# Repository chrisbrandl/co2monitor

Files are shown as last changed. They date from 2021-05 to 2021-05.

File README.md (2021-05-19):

# co2monitor

An IoT project to counter the spread of Covid19 indoors. 

Scientific Background: https://pubs.acs.org/doi/10.1021/acs.estlett.1c00183

There are lots of projects online that describe the basic setup to using a specific sensor for that, but they are mostly somewhat incomplete for practical use.

For this CO2 sensor project, a display is added to stay informed on the spot along with a colored light indicator to prominently indicate the severity of the current situation.

Furthermore, to have a record of the measurements and an easy means to analyse the incoming data, some MQTT functionality has been added to utimately rout the data e.g. into the ADAMOS IoT Platform, which enables me to automatically trigger actors based on the level of readings from this sensor.

# Hardware

The project 
- is run by an ESP8266 Mini D1
- leverages a MH-Z19 B/C sensor which measures the concentration of CO2 in ppm
- includes an OLED 128x64 display for showing the current readings
- uses a small 12xLED Ring to indicate the current conditions regarding the measured CO2 concentration
- Protoboard for integrating all wiring

# Wiring

Check the checked-in fritzing image for wiring illustration.

<table>
    <tr>
      <td>ESP</td><td>MHZ19</td> <td>OLED</td> <td>LEDRing</td>
    </tr>
    <tr>
      <td>5V</td> <td>VIN</td>---<td>VDD</td>---<td>VIN</td>
    </tr>
    <tr>
      <td>G</td> <td>GND</td>---<td>GND</td>---<td>GND</td>
    </tr>
    <tr>
      <td>D1</td> <td>---</td> <td>SCK</td> <td>---</td> 
    </tr>
    <tr>
      <td>D2</td> <td>---</td> <td>SDA</td> <td>---</td> 
    </tr>
    <tr>
      <td>D3</td> <td>TX</td> <td>---</td><td>---</td> 
    </tr>
    <tr>
      <td>D4</td> <td>RX</td> <td>---</td><td>---</td> 
    </tr>
    <tr>
      <td>D5</td> <td>---</td><td>---</td> <td>IN</td>
    </tr>
</table>

# Code

See the code in the master branch, need to add WLAN access point credentials and MQTT details. 
The following library is used for the sensor (alternatively you could also call the values via the SoftwareSerial (MH_Z19_RX, MH_Z19_TX)): 

https://github.com/WifWaf/MH-Z19 

Advantage of the library: takes care of autocalibration.

# 3D Model

This project is re-using this great modular 3D model for IoT devices:

https://www.thingiverse.com/thing:3391397

The dome part has been modified to ensure free circulation of air around the sensor, see checked-in STL file. 
The model is printed e.g. on a standard Ender 3 printer.

# Dashboarding 

Once the data is being sent to an MQTT Server, it can be used via Node Red to be forwarded to the e.g. ADAMOS IIoT Platform. 

These are some basic steps on Node Red:

* Subscribe to MQTT Topic  
* Build JSON payload
* POST to ADAMOS IIoT Tenant as measurement
* Add widget for incoming data points on IoT platform

Resulting UI screenshot is available in the Repository.

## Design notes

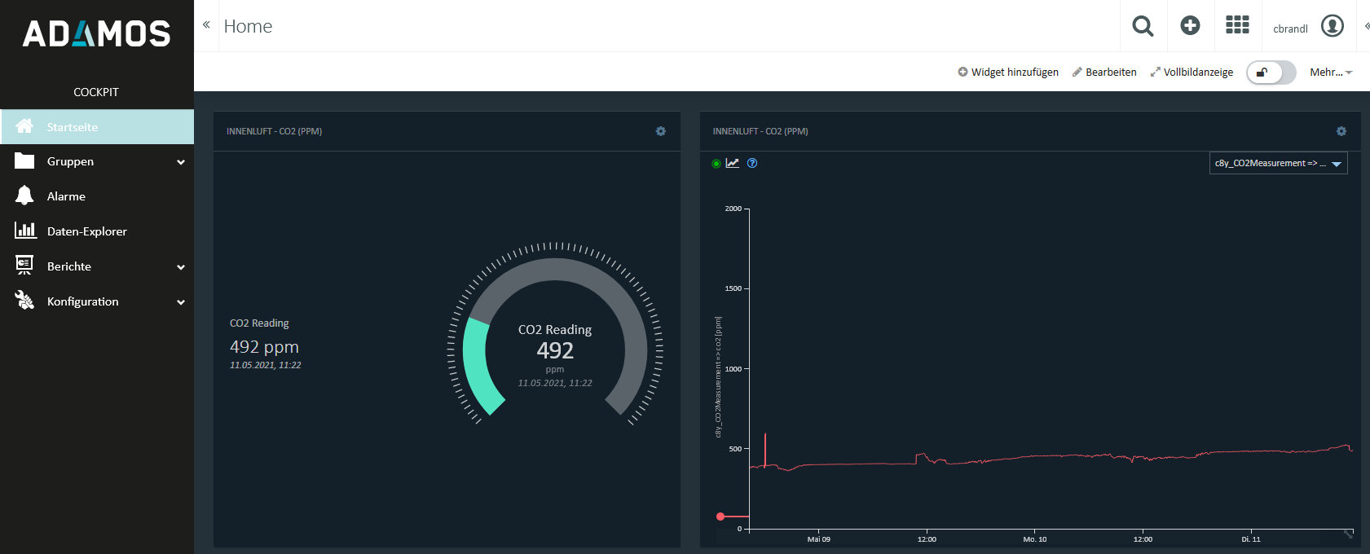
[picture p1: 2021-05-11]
ADAMOSDashboard.png

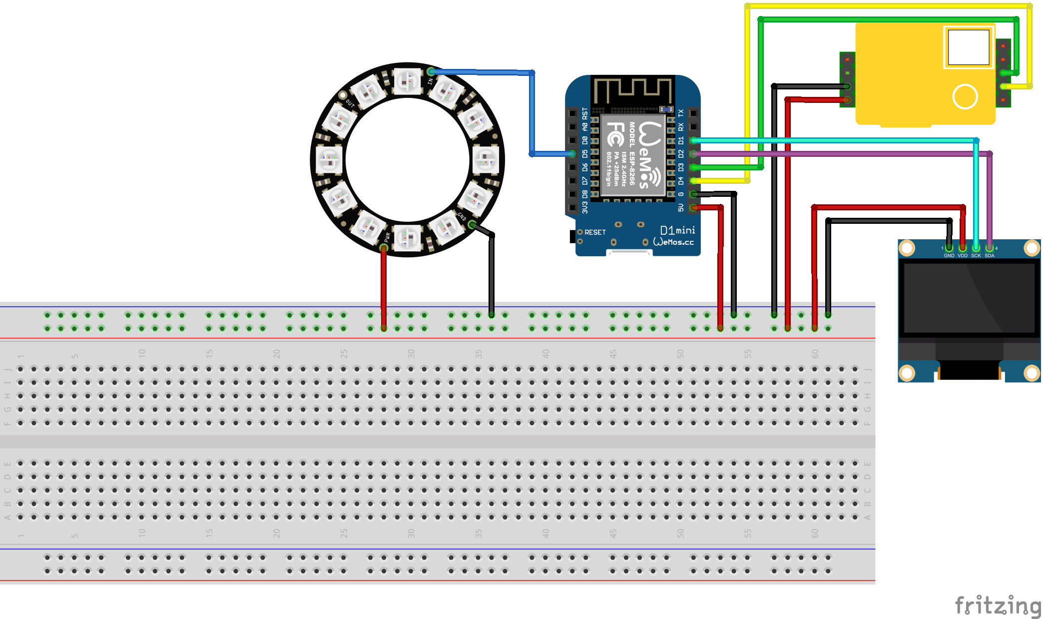
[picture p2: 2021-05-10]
MHZ19_Steckplatine.png

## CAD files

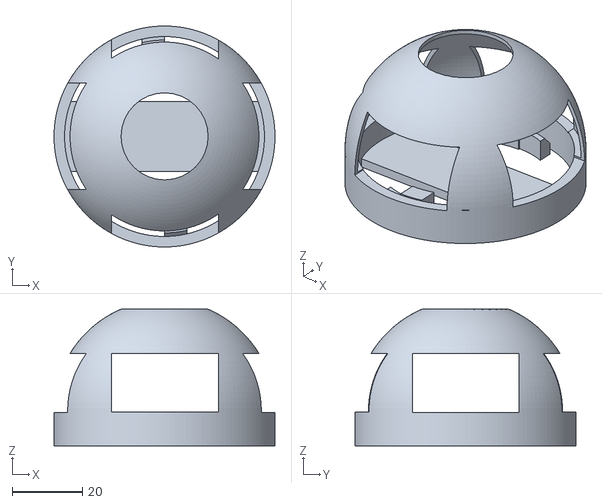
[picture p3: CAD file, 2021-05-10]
modified_dome.stl
62.8 x 62.8 x 38.9

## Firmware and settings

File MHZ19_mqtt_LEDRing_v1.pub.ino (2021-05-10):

#include <Arduino.h>
#include "MHZ19.h"                                        
#include <SoftwareSerial.h>
#include <Adafruit_GFX.h>
#include <Adafruit_SSD1306.h>
#include <ESP8266WiFi.h>
#include <PubSubClient.h>
#include <Wire.h>

#define RX_PIN 0         //MH-Z19 RX-PIN                                         
#define TX_PIN 2         //MH-Z19 TX-PIN                                   
#define SCL_PIN 5         //OLED SCL-PIN                                         
#define SDA_PIN 4         //OLED SDA-PIN                                   
#define BAUDRATE 9600    //Terminal Baudrate
#define SCHWELLE 1500 //Schwellwert wenn die LED von Gelb auf Rot wechseln soll.
#define RICHTWERT 1000 //Schwellwert wenn die LED von Grün auf Gelb wechseln soll.
#define OLED_RESET -1  // GPIO0 , -1 not used

//Klassen definierung
MHZ19 myMHZ19;                               
SoftwareSerial mySerial(RX_PIN, TX_PIN); 
unsigned long getDataTimer = 0;
int CO2 = 0; 
int8_t Temp = 0;
int CO2MaxPerDay = 0;
int CO2MaxOverall = 0;
int CO2AvgPerDay = 0;
int CO2AvgOverall = 0;
int readCounter = 0;
unsigned long getSendingTimer = 0;

// Wifi setup
#define WLAN_SSID  "******" 
#define WLAN_PASS  "******" 

#include <ESP8266WiFi.h>
#include <ESP8266HTTPClient.h>
WiFiClient client; 
#define MQTT_NAME "MQTTNAME" 
#include <PubSubClient.h>
const char* MQTT_BROKER = "******";
PubSubClient mqttClient(client);
long lastMsg = 0;
char msg[50];
int value = 0;

// Define NTP Client to get time
#include "NTPClient.h"
#include "WiFiUdp.h"
const long utcOffsetInSeconds = 3600;
char daysOfTheWeek[7][12] = {"Sunday", "Monday", "Tuesday", "Wednesday", "Thursday", "Friday", "Saturday"};
//WiFiUDP ntpUDP;
//NTPClient timeClient(ntpUDP, "pool.ntp.org", utcOffsetInSeconds);

#include <Adafruit_NeoPixel.h>
#define PIN D5
#define NUMPIXELS 12
#define DELAYVAL 100 // Time (in milliseconds) to pause between pixels
#define BRIGHTNESS 10 // change brightness here – 255 for full brightness
int R = 253;
int G = 255;
int B = 56;
Adafruit_NeoPixel pixels(NUMPIXELS, PIN, NEO_GRB + NEO_KHZ800);

// OLED Display 128x64 
Adafruit_SSD1306 display(128, 64, &Wire, OLED_RESET);

void setup(){
  Serial.begin(115200);
  delay(500);
  Serial.println("Start");
    //LED PIN Mode festlegen
  pixels.begin(); // INITIALIZE NeoPixel strip object (REQUIRED)
  for(int i=0; i<NUMPIXELS; i++) { // For each pixel...
    pixels.setPixelColor(i, pixels.Color(R,G,B)); 
    pixels.setBrightness(BRIGHTNESS);
    pixels.show();   // Send the updated pixel colors to the hardware.
  }
    
  display.begin(SSD1306_SWITCHCAPVCC, 0x3C);  // initialize with the I2C addr //0x3D (128x64), 0x3C (for the 64x48)
  
  display.clearDisplay();
  display.setTextColor(WHITE);
  display.setTextSize(1);
  display.setCursor(0,0);
  display.println("Connecting...");
  display.display();    
  delay(500);

  //Serielle Intialisierung
  mySerial.begin(BAUDRATE);                   
  myMHZ19.begin(mySerial);
  myMHZ19.autoCalibration(); // Turn auto calibration ON (OFF autoCalibration(false))

  delay(1000);

    /* Alternative manual calibration
    myMHZ19.autoCalibration(false);     // make sure auto calibration is off
    Serial.print("ABC Status: "); myMHZ19.getABC() ? Serial.println("ON") :  Serial.println("OFF");  // now print it's status
    Serial.println("Waiting 20 minutes to stabalise...");
   // if you don't need to wait (it's already been this amount of time), remove the 2 lines 
    timeElapse = 12e5;   //  20 minutes in milliseconds
    delay(timeElapse);    //  wait this duration
    Serial.println("Calibrating..");
    myMHZ19.calibrate();    // Take a reading which be used as the zero point for 400 ppm 
    */
    
  connectToWiFi(); 

  mqttClient.setServer(MQTT_BROKER, 1883);
  //mqttClient.setCallback(callback);
  while (!mqttClient.connected()) {
    Serial.print("MQTT ");
    if (mqttClient.connect(MQTT_NAME)) {
      Serial.println("connected");  
    } else {
      Serial.print("failed with state ");
      Serial.print(mqttClient.state());
      delay(2000);
    }
  }
  //timeClient.begin();
  delay(1000);
}

void loop() {

  //Prüfung ob 2 Sekunden um sind.
  if (millis() - getDataTimer >= 2000){
    CO2 = myMHZ19.getCO2();
    readCounter++;
    CO2AvgOverall = (CO2AvgOverall + CO2) / readCounter;
    if (CO2 > CO2MaxPerDay) {
      CO2MaxPerDay = CO2;
    }
    if (CO2 > CO2MaxOverall) {
      CO2MaxOverall = CO2;
    }
    if (CO2 > SCHWELLE) { 
        R = 255;
        G = 0;
        B = 0;
    } else if (CO2 > RICHTWERT) { 
        R = 255;
        G = 127;
        B = 80;
    } else if (CO2 == 0) {
        R = 255;
        G = 255;
        B = 0;
    } else {
        R = 0;
        G = 255;
        B = 0;
    }
    //Ausgabe auf den Seriellen Monitor
    Serial.print("CO2 (ppm): ");
    Serial.println(CO2);

    Temp = myMHZ19.getTemperature();                     
    // Request Temperature (as Celsius)
    Serial.print("Temperature (C): ");                  
    Serial.println(Temp);                               

    getDataTimer = millis();
    display.clearDisplay();
    display.setTextColor(WHITE);
    display.setTextSize(2);
    //display.setFont(&FreeSans12pt7b);
    display.setCursor(0,0);
    display.print("CO2: ");
    display.println(CO2);
    display.setCursor(0,17);
    display.print("Max: ");
    display.println(CO2MaxOverall);
    display.setCursor(0,34);
    display.print("Temp: ");
    display.println(Temp);
    display.display();  

    for(int i=0; i<NUMPIXELS; i++) { // For each pixel...
      pixels.setPixelColor(i, pixels.Color(R,G,B)); 
      pixels.setBrightness(BRIGHTNESS);
      pixels.show();   // Send the updated pixel colors to the hardware.
    }
  }
  if (millis() - getSendingTimer >= 60000) {
    int str_len = String(CO2).length() + 1; 
    // Prepare the character array (the buffer) 
    char char_array[str_len];
    String(CO2).toCharArray(char_array, str_len);
    if(! mqttClient.connected()) {
      if (mqttClient.connect("coronx")) {
        Serial.println("connected");  
      } else {
        Serial.print("failed with state ");
        Serial.print(mqttClient.state());
        delay(2000);
      }
    } 
    mqttClient.publish("data/co2", char_array);
    Serial.print("Publish (CO2) to mqtt = ");
    Serial.println(char_array);

    int str_len2 = String(Temp).length() + 1; 
    char char_array2[str_len2];
    String(Temp).toCharArray(char_array2, str_len2);
    mqttClient.publish("data/temp", char_array2);
    Serial.print("Publish (Temp) to mqtt = ");
    Serial.println(char_array2);

    getSendingTimer = millis();
  }
  delay(1000);  
}

void connectToWiFi() { 
  // Connect to WiFi access point. 
  delay(10); 
  Serial.print(F("Connecting to ")); 
  Serial.println(WLAN_SSID); 
  WiFi.begin(WLAN_SSID, WLAN_PASS); 
  int timeoutCounter = 0;
  while ( WiFi.status() != WL_CONNECTED && timeoutCounter <= 12) {
    //sometimes it is not connecting properly
    timeoutCounter++;
    Serial.print(".");
    delay(500);
  }
  if ( WiFi.status() != WL_CONNECTED ) {
    Serial.println(F("NOT connected!")); 
    //Serial.println("Restarting ESP as WiFi can not connect"); 
    //ESP.restart();
  } else {
    Serial.println(F("WiFi connected!")); 
  }
} 

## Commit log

2021-05-10 wiring added
2021-05-10 STL added
    [modified_dome.stl]
